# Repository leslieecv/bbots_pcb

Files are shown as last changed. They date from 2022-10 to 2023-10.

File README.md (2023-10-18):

# PCB Battlebots base

Este repositorio contiene las diferentes versiones de placa base, diseñadas para el curso [Battlebots](https://github.com/Battlebots-UChile) de la FCFM Uchile.
Fueron desarrolladas usando EAGLE y se complementa con el diseño

- pcbv1: utiliza Arduino UNO (funcional). Otros detalles disponibles en [Battlebot-base-testing](https://github.com/uwulises/Battlebot-base-testing).
- pcbv2: utiliza NodeMCU Amica V2 (ESP8266) y opcionalmente puede usar un Módulo Wifi ESP8266 ESP-07 (incompleta).
- pcbv3: utiliza solamente NodeMCU Amica V2 (ESP8266) (funcional). Diseño mecánico disponible en [MobileBase_ESP8266](https://github.com/uwulises/MobileBase_ESP8266).

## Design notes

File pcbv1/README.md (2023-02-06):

# Placa Battlebots 

Hola, soy una placa que busca integrar los componentes del BattleBot base entregado a estudiantes del curso Módulo Interdisciplinario - Battlebots 2022.

La placa considera la conexión con los siguiente componentes:
- Arduino UNO (1)
- Driver Puente H L9110S (2)
- Módulo Bluetooth HC-06 (1)
- Regulador de voltaje LM2596 (1)
- Regulador de voltaje LM2596 Mini (1)
- Batería LiPo de 7.4V (1)

Adicionalmente, se tienen componentes accesorios:
- Led SMD 0805 (2)
- Resistencia SMD 0805 de 0.5-1kOhm (2)
- Diodo (1)

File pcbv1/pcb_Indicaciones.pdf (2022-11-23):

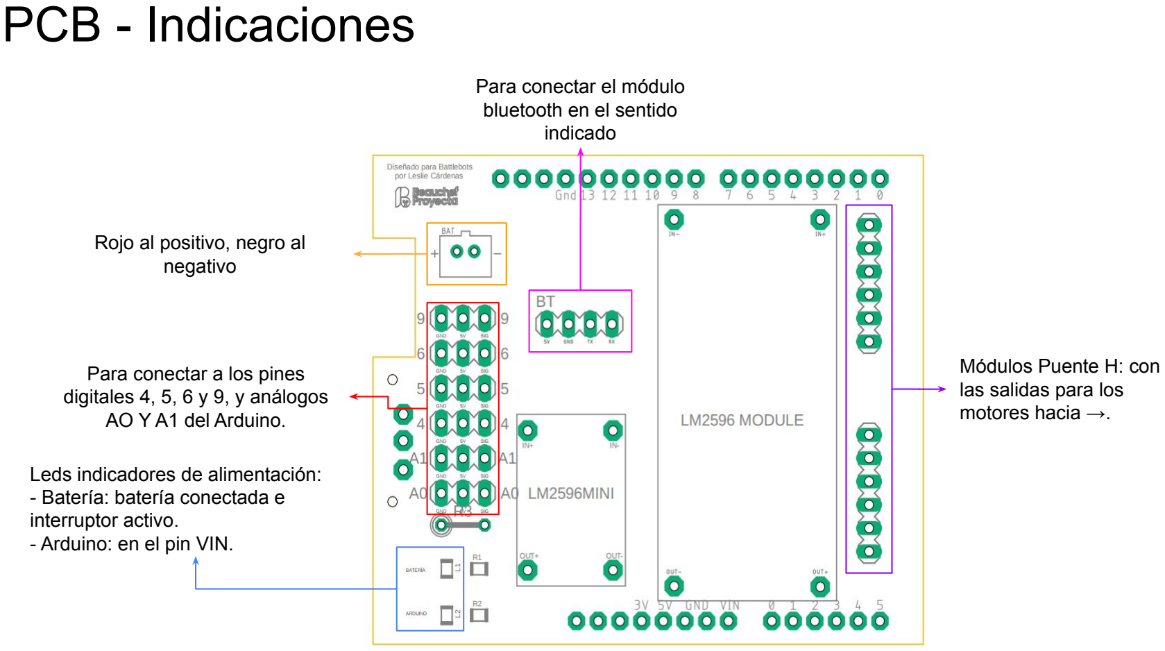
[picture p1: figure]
Para conectar a los pines digitales 4, 5, 6 y 9, y análogos AO Y A1 del Arduino.; Rojo al positivo, negro al negativo; Leds indicadores de alimentación: - Batería: batería conectada e interruptor activo. - Arduino: en el pin VIN.; Módulos Puente H: con las salidas para los motores hacia →.; Para conectar el módulo bluetooth en el sentido indicado; PCB - Indicaciones

# PCB - Puente H y conexiones con motores

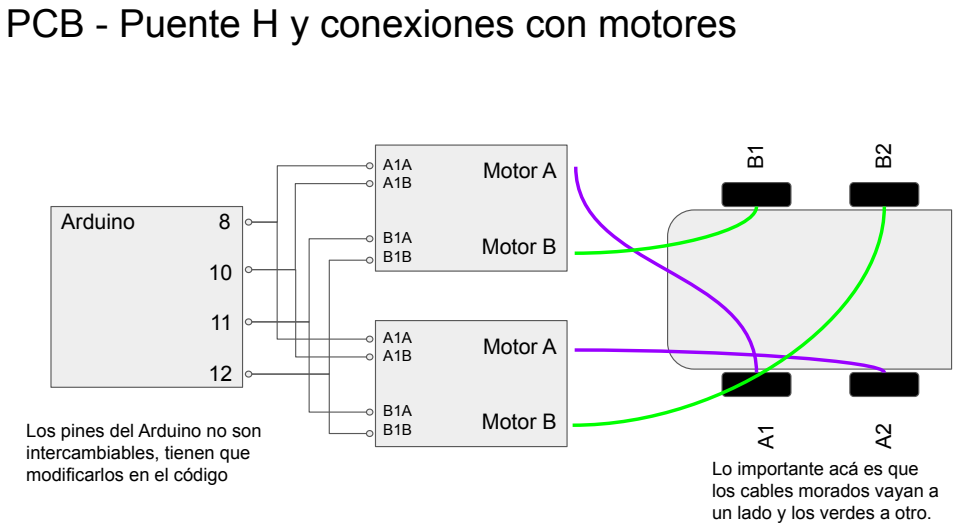
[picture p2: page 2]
Motor A; Motor B; Arduino; Los pines del Arduino no son; modificarlos en el código; Lo importante acá es que

intercambiables, tienen que

los cables morados vayan a
un lado y los verdes a otro.

# PCB - Módulo Bluetooth

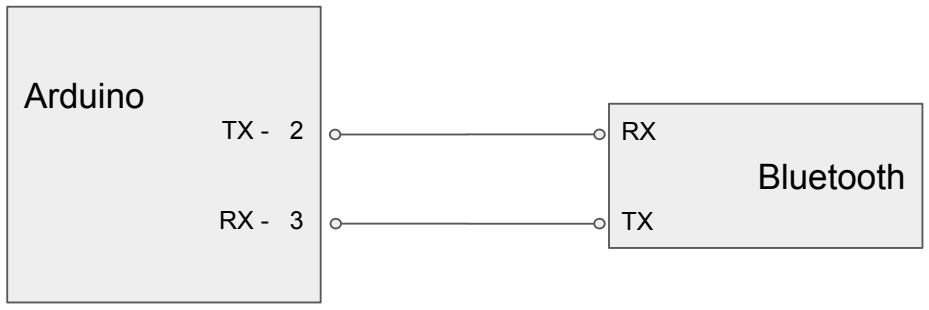
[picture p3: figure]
Bluetooth; Arduino

### Deben usar la librería SofwareSerial para configurar los pines 2 y 3 del

Arduino como TX y RX,

### respectivamente

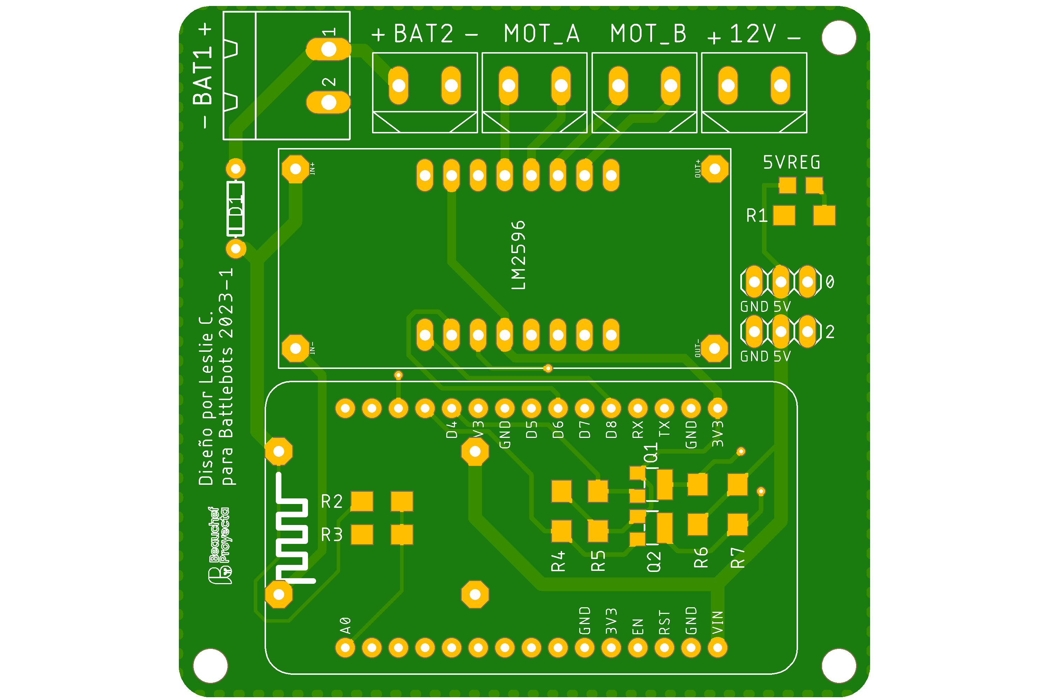
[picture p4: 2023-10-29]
pcbv3/top.png

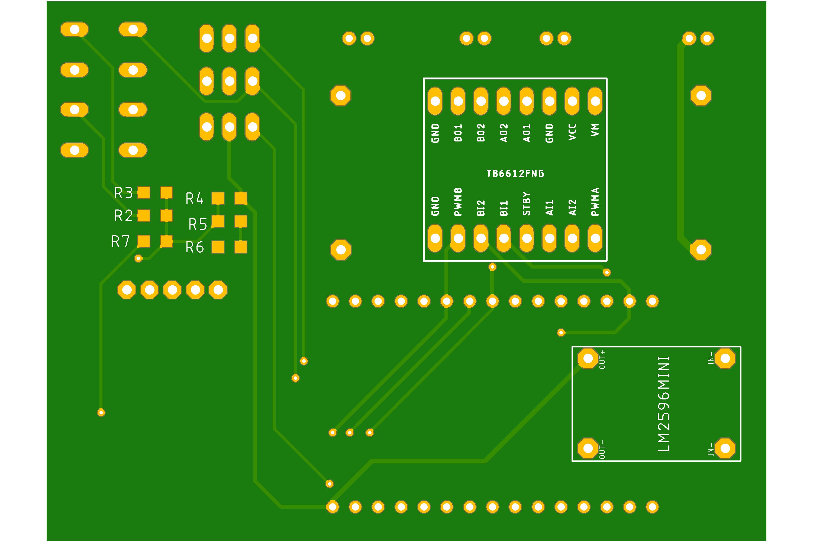
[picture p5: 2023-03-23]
pcbv2/bbotsv2_bottom.png

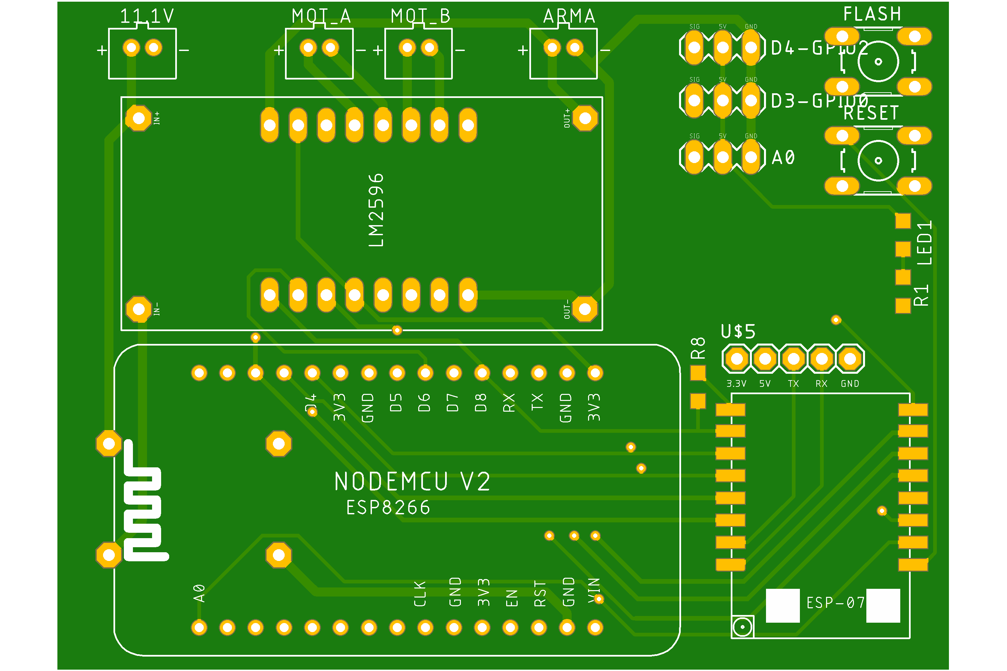
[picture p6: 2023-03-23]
pcbv2/bbotsv2_top.png

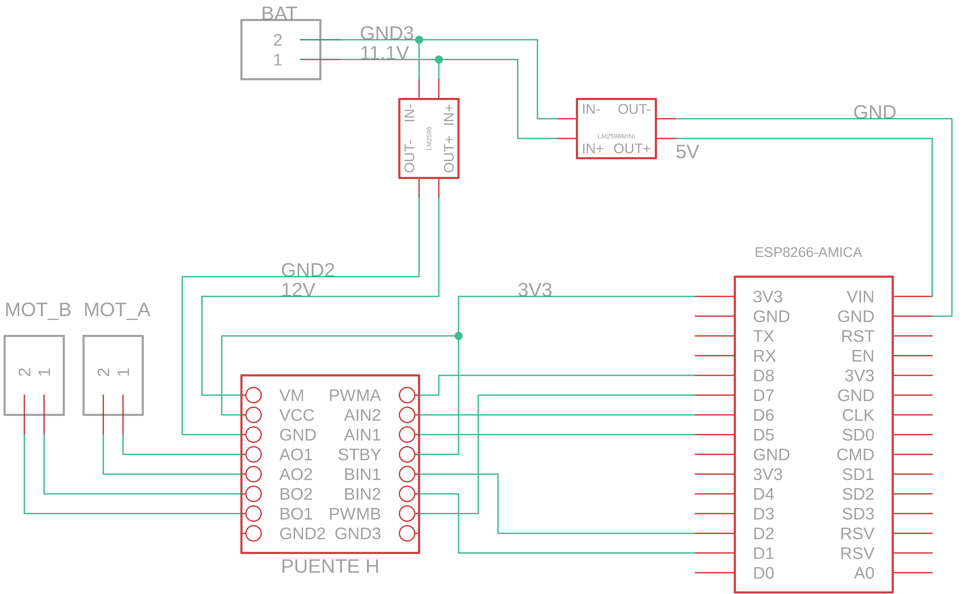
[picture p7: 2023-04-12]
prepcb diagram/diagram_light.png

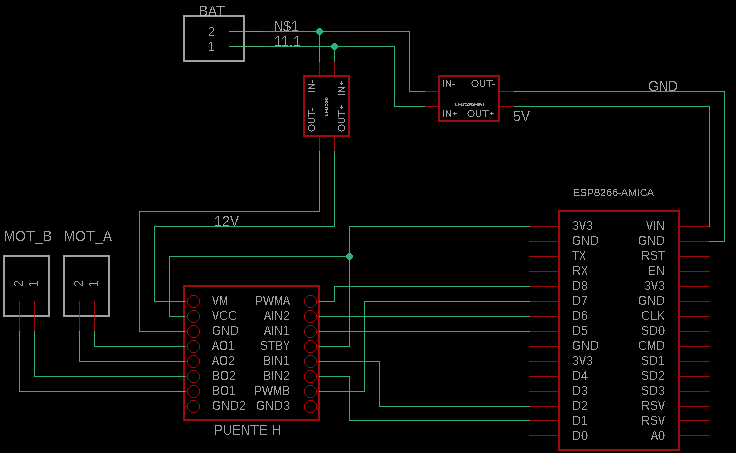
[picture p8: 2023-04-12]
prepcb diagram/diagram.png

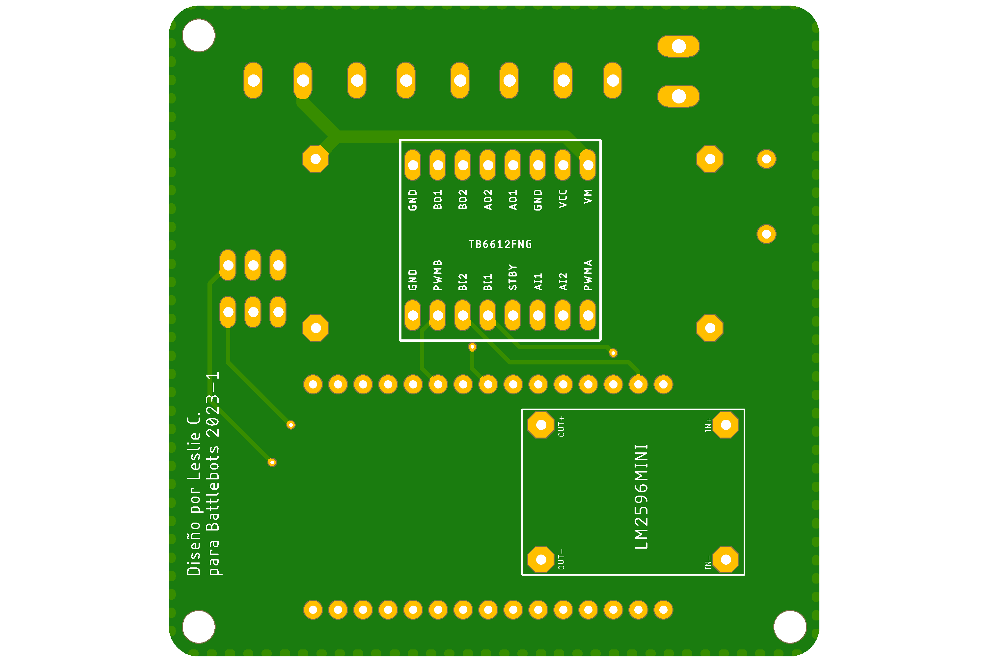
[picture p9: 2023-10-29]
pcbv3/bottom.png

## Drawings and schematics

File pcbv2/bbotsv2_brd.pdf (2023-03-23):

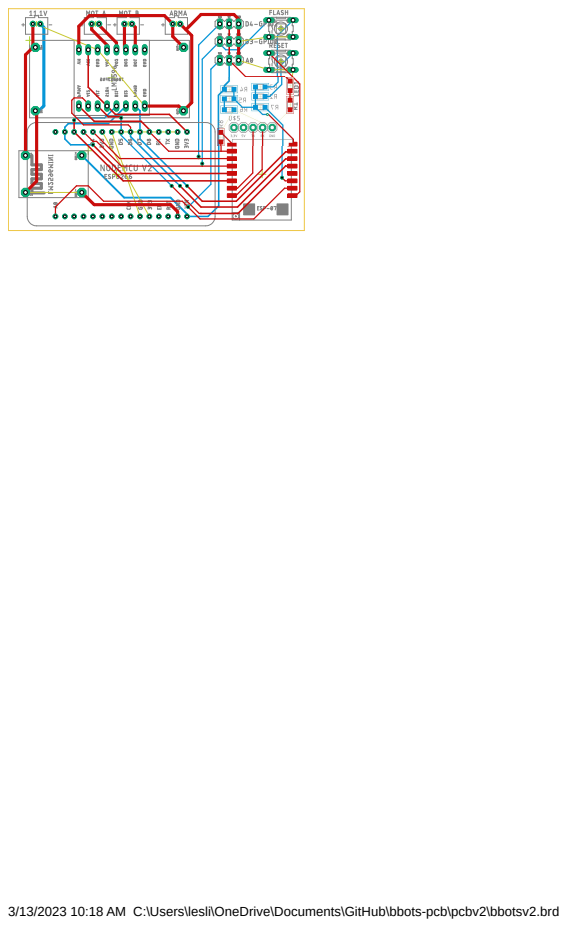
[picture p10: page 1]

3/13/2023 10:18 AM C:\Users\lesli\OneDrive\Documents\GitHub\bbots-pcb\pcbv2\bbotsv2.brd

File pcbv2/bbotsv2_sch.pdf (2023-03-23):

# 4 2 FLASHR³

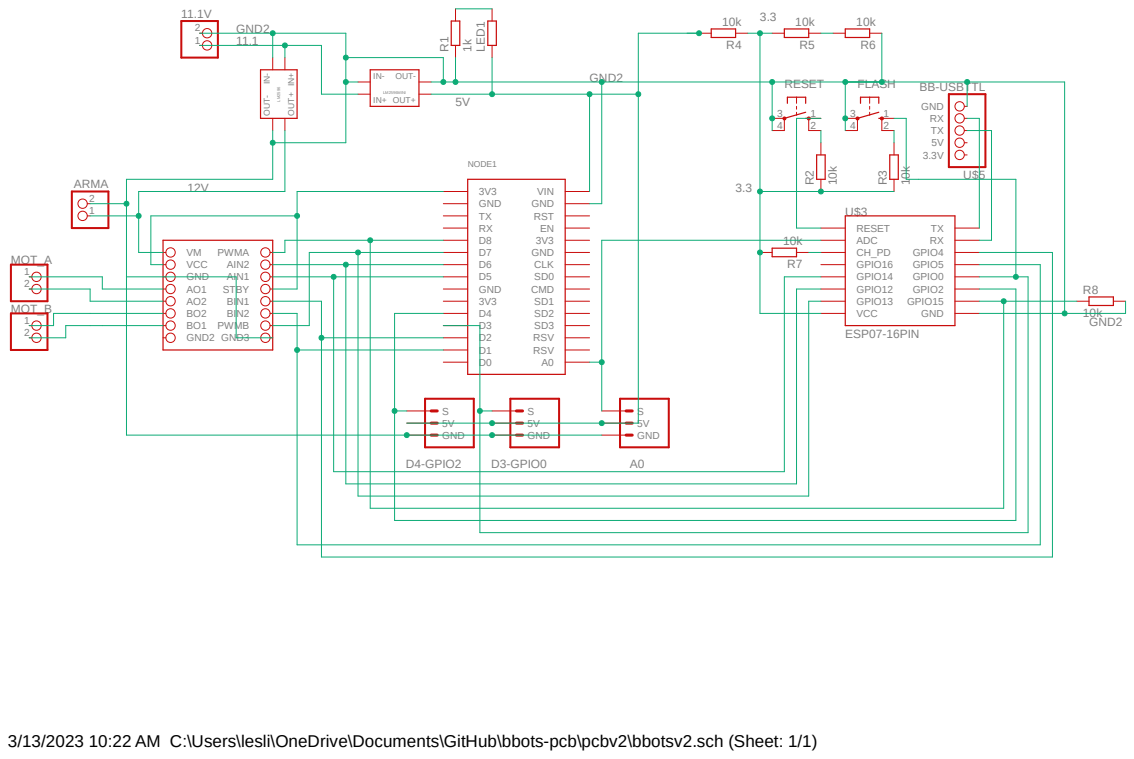
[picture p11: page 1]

NODE1 IN⁺ OUT+ IN⁻ OUT⁻ LM²⁵⁹⁶

3/13/2023 10:22 AM C:\Users\lesli\OneDrive\Documents\GitHub\bbots-pcb\pcbv2\bbotsv2.sch (Sheet: 1/1)

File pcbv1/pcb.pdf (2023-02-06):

# Diseñado para Battlebots por Leslie Cárdenas

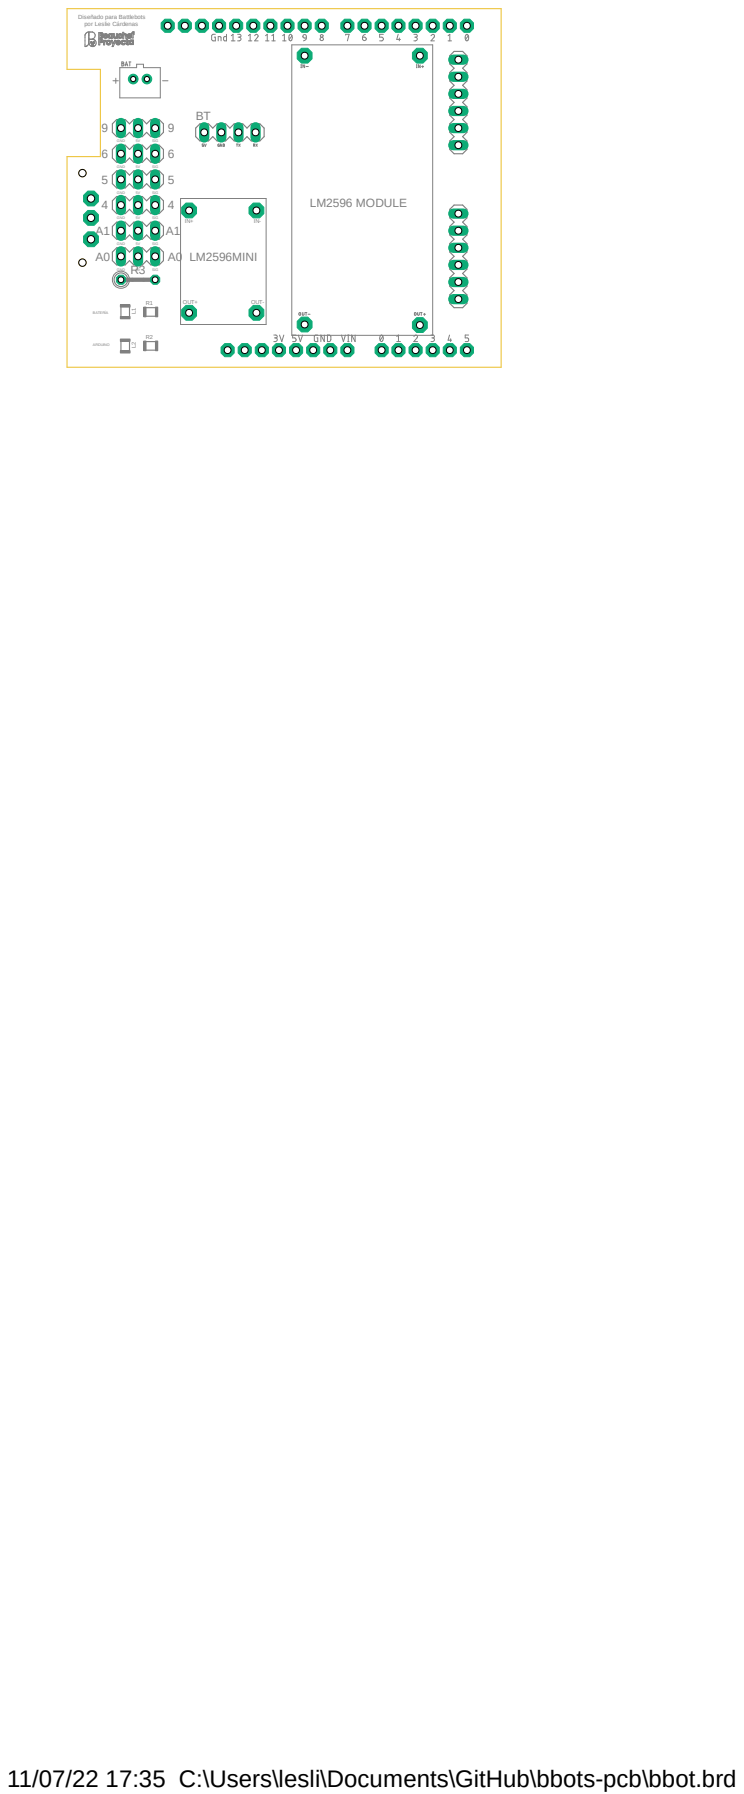
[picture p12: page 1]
ARDUINO; BATERÍA; OUT+; OUT-; LM2596MINI; GND; SIG; LM2596 MODULE

11/07/22 17:35 C:\Users\lesli\Documents\GitHub\bbots-pcb\bbot.brd

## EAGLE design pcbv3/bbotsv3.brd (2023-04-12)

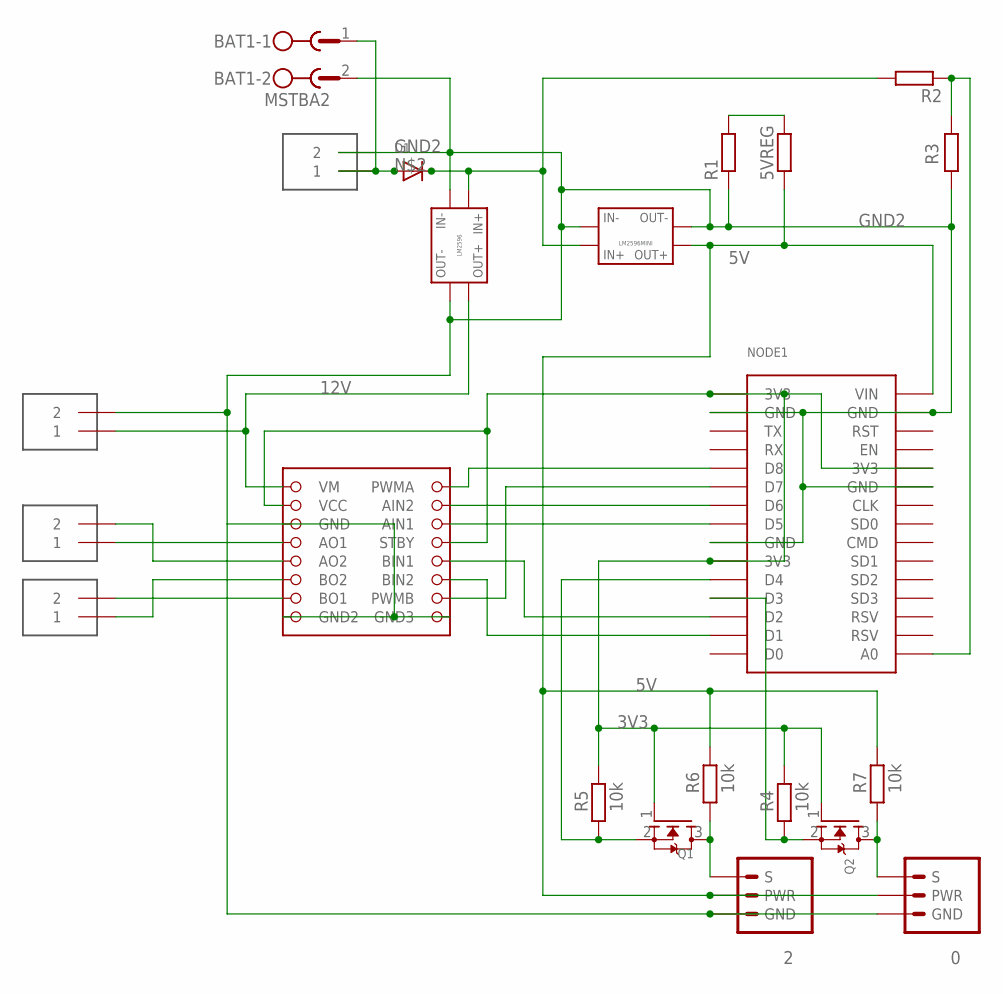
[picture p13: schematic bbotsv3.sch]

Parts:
0, 2: BB-PIN3BB-PIN3; 1X03
5VREG: BB-R0805; R0805
ARMA, ARMA1, ARMA2, ARMA3: TERMINAL_2P; KF301-2P
BAT1: MSTBA2
D1: DIODEDO-1N4148; DO-1N4148
NODE1: NODEMCU_ESP8266
Q1, Q2: MOSFET-NWAVE; SOT23-W
R1: 100; R1206
R2, R4, R5, R6, R7: 10k; R1206
R3: 1k; R1206
U$1: BB-LM2596
U$2: BB-TB6612
U$3: BB-LM2596MINILM2596MINIV2; LM2596MINIV2

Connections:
3V3: NODE1.3V3@1 (3V3), NODE1.3V3@2 (3V3), NODE1.3V3@3 (3V3), Q1.1 (G), Q2.1 (G), R4.2, R5.2, U$2.STBY, U$2.VCC
5V: 0.P (PWR), 2.P (PWR), 5VREG.1, NODE1.VIN, R6.2, R7.2, U$3.OUT+
11.1: D1.C, R2.2, U$1.IN+, U$3.IN+
12V: ARMA.1, U$1.OUT+, U$2.VM
GND2: 0.GND, 2.GND, ARMA.2, ARMA3.2, BAT1.2, NODE1.GND@1 (GND), NODE1.GND@2 (GND), NODE1.GND@3 (GND), NODE1.GND@4 (GND), R1.1, R3.2, U$1.IN-, U$1.OUT-, U$2.GND, U$2.GND2, U$2.GND3, U$3.IN-, U$3.OUT-
unnamed: NODE1.A0, R2.1, R3.1
unnamed: ARMA3.1, BAT1.1, D1.A
unnamed: 5VREG.2, R1.2
unnamed: NODE1.D8, U$2.PWMA
unnamed: NODE1.D7, U$2.PWMB
unnamed: ARMA2.1, U$2.BO2
unnamed: NODE1.D6, U$2.AI2 (AIN2)
unnamed: NODE1.D5, U$2.AI1 (AIN1)
unnamed: NODE1.D2, U$2.BI1 (BIN1)
unnamed: NODE1.D1, U$2.BI2 (BIN2)
unnamed: 2.S, Q1.3 (D), R6.1
unnamed: NODE1.D3, Q2.2 (S), R4.1
unnamed: ARMA1.2, U$2.AO2
unnamed: ARMA1.1, U$2.AO1
unnamed: ARMA2.2, U$2.BO1
unnamed: 0.S, Q2.3 (D), R7.1
unnamed: NODE1.D4, Q1.2 (S), R5.1

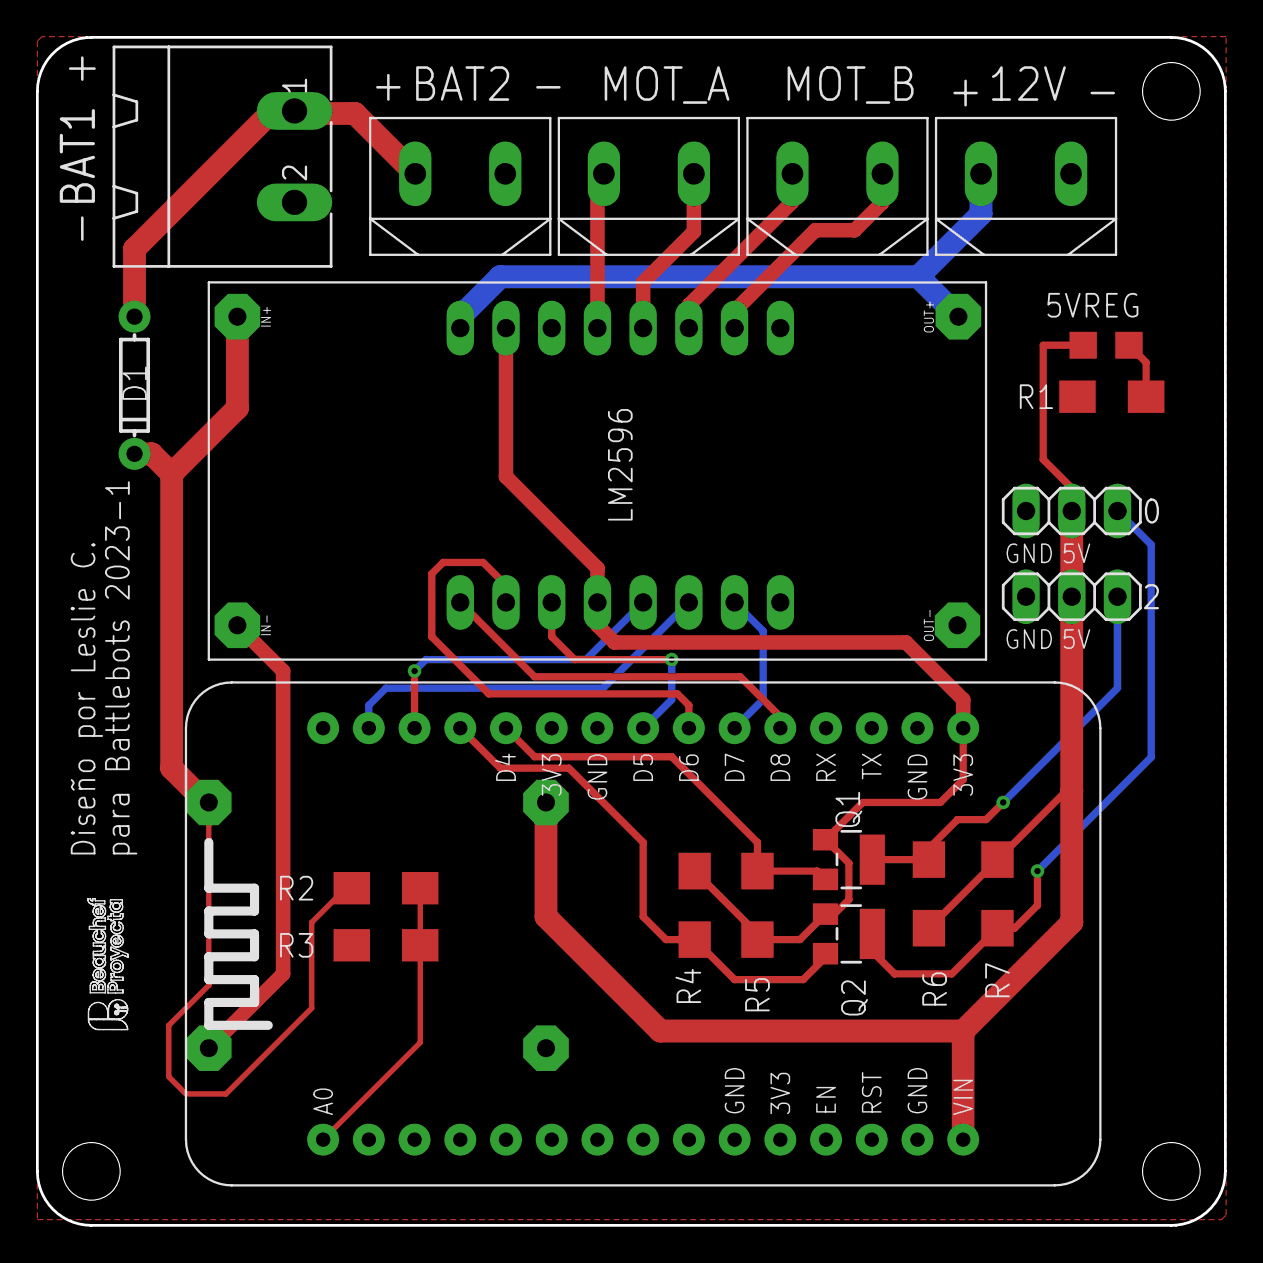
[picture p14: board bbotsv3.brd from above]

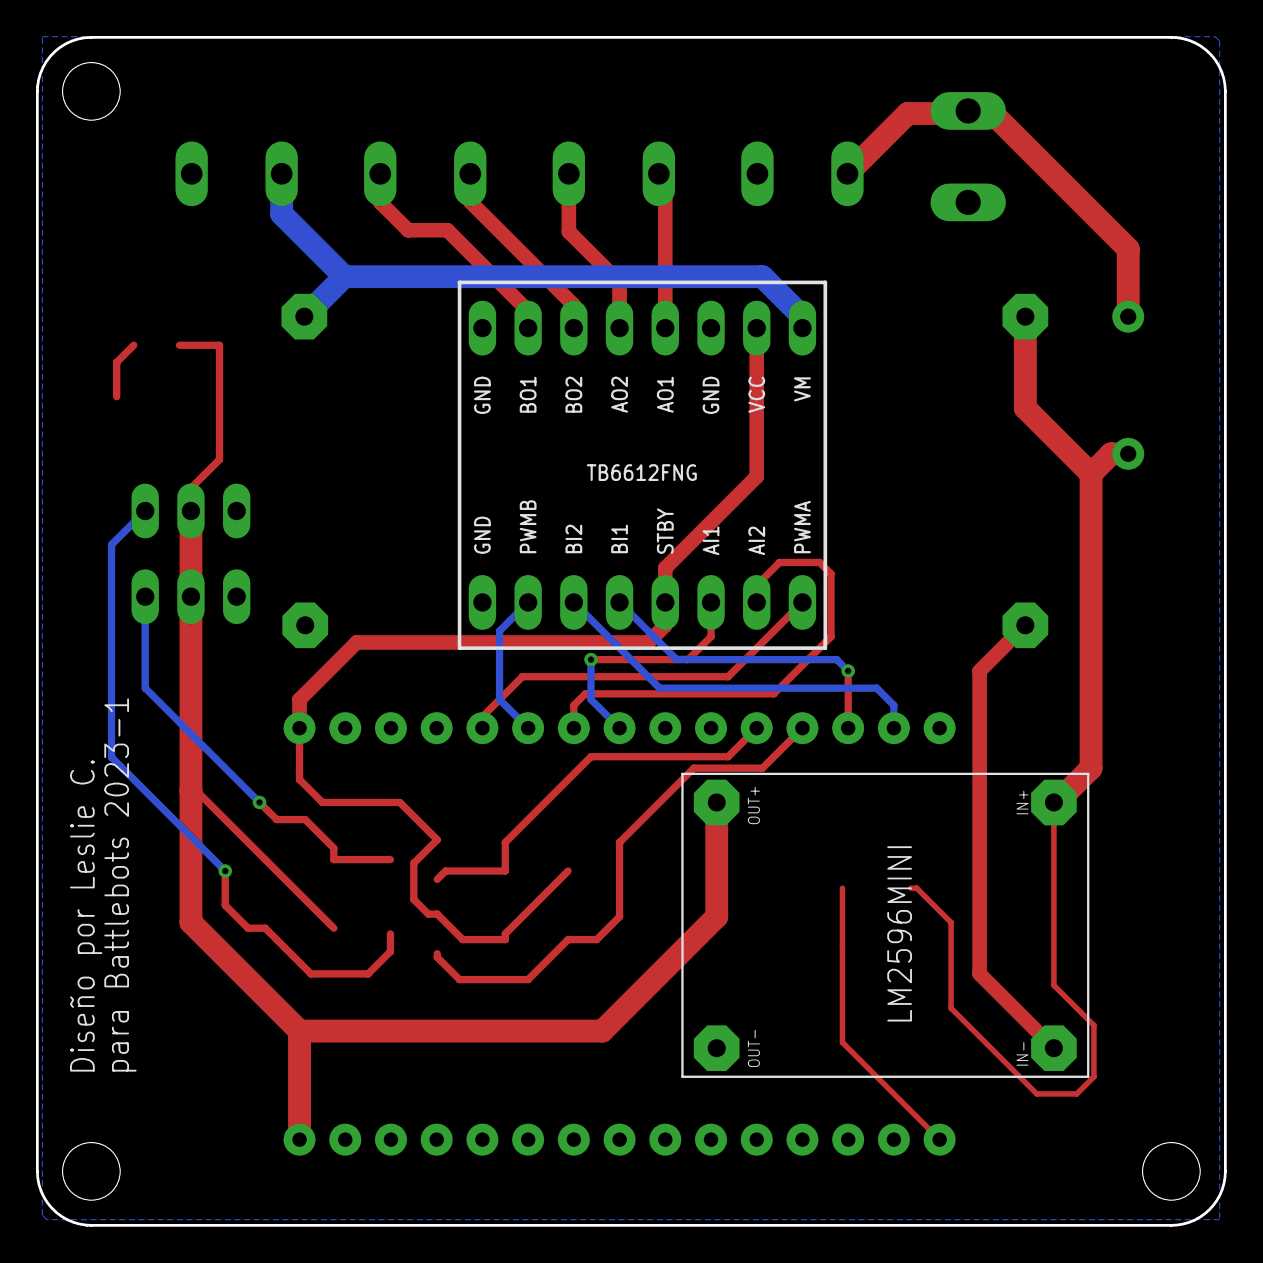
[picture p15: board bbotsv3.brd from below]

Board: 2 copper layers, 66.0 x 66.0 mm, 22 parts (2 on the bottom side), 22 nets.

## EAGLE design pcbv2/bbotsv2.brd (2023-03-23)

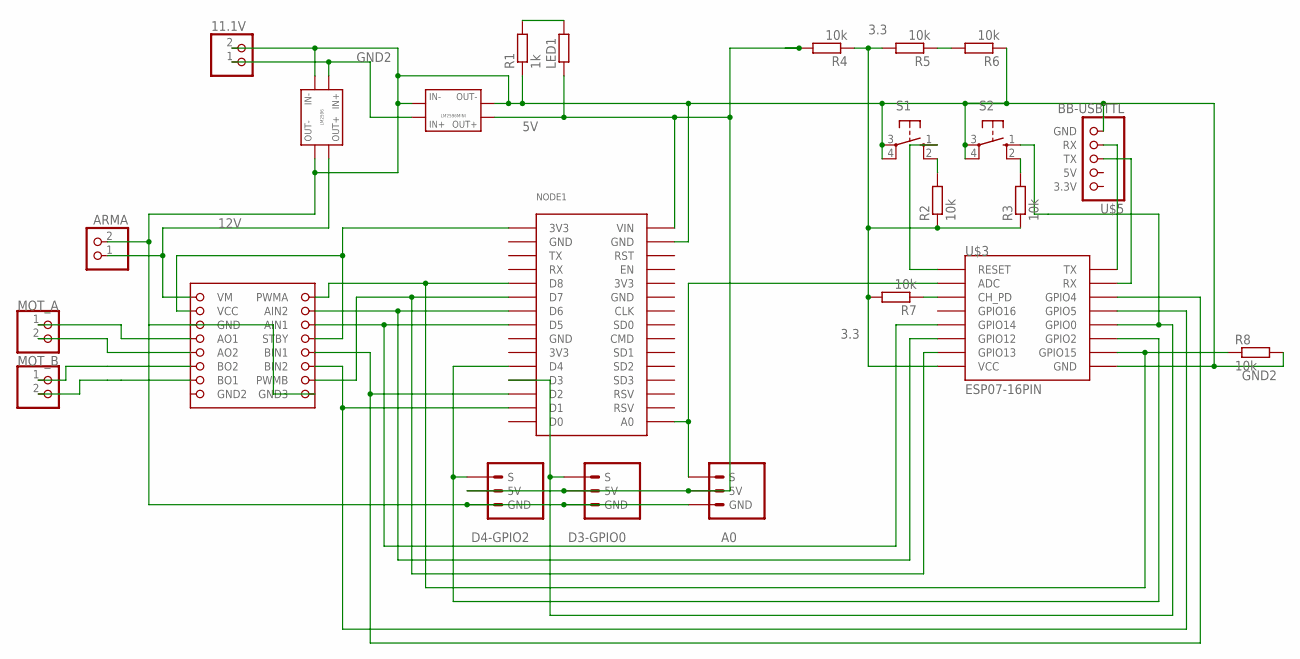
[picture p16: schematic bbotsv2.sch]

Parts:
11.1V: JST_2PIN-THM; JST-PH-2-THM
A0: BB-PIN3
ARMA: JST_2PIN-THM; JST-PH-2-THM
D3-GPIO0, D4-GPIO2: BB-PIN3
LED1: BB-RESM0805; M0805
MOT_A: JST_2PIN-THM; JST-PH-2-THM
MOT_B: JST_2PIN-THM; JST-PH-2-THM
NODE1: NODEMCU_ESP8266
R1: 1k; M0805
R2, R3, R4, R5, R6, R7, R8: 10k; M0805
S1, S2: 10-XX; B3F-10XX
U$1: BB-LM2596
U$2: BB-TB6612
U$3: ESP07-16PIN
U$4: BB-LM2596MINI
U$5: BB-USBTTL; 1X05

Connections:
3.3: R2.1, R3.1, R4.1, R5.2, R7.2, U$3.VCC
3V3: NODE1.3V3@2 (3V3), NODE1.3V3@3 (3V3)
5V: A0.2 (5V), D3-GPIO0.2 (5V), D4-GPIO2.2 (5V), LED1.1, NODE1.VIN, R4.2, U$4.OUT+
11.1: 11.1V.1 (2), U$1.IN+, U$4.IN+
12V: ARMA.1 (2), U$1.OUT+, U$2.VM
GND: NODE1.GND@1 (GND), NODE1.GND@2 (GND), NODE1.GND@3 (GND)
GND2: 11.1V.2 (1), A0.1 (GND), ARMA.2 (1), D3-GPIO0.1 (GND), D4-GPIO2.1 (GND), NODE1.GND@4 (GND), R1.1, R6.1, R8.2, S1.3, S1.4 (P1), S2.3, S2.4 (P1), U$1.IN-, U$1.OUT-, U$2.GND, U$2.GND3, U$3.GND, U$4.IN-, U$4.OUT-, U$5.GND; also elsewhere on the board
unnamed: LED1.2, R1.2
unnamed: NODE1.D8, R8.1, U$2.PWMA, U$3.GPIO15
unnamed: NODE1.D7, U$2.PWMB, U$3.GPIO13
unnamed: NODE1.D6, U$2.AI2 (AIN2), U$3.GPIO12
unnamed: NODE1.D5, U$2.AI1 (AIN1), U$3.GPIO14
unnamed: NODE1.D2, U$2.BI1 (BIN1), U$3.GPIO4
unnamed: NODE1.D1, U$2.BI2 (BIN2), U$3.GPIO5
unnamed: D4-GPIO2.3 (S), NODE1.D4, U$3.GPIO2
unnamed: MOT_A.2 (1), U$2.AO2
unnamed: MOT_A.1 (2), U$2.AO1
unnamed: MOT_B.1 (2), U$2.BO2
unnamed: MOT_B.2 (1), U$2.BO1
unnamed: NODE1.3V3@1 (3V3), U$2.STBY, U$2.VCC
unnamed 20: D3-GPIO0.3 (S), NODE1.D3, S2.1 (S), U$3.GPIO0; also elsewhere on the board
unnamed: U$3.TX, U$5.RX
unnamed: U$3.RX, U$5.TX
unnamed: A0.3 (S), NODE1.A0, U$3.ADC
unnamed 24: R2.2, S1.2 (S1); also elsewhere on the board
unnamed 25: R3.2, S2.2 (S1); also elsewhere on the board
unnamed: R5.1, R6.2
unnamed 27: S1.1 (S), U$3.REST (RESET); also elsewhere on the board
unnamed: R7.1, U$3.CH_PD

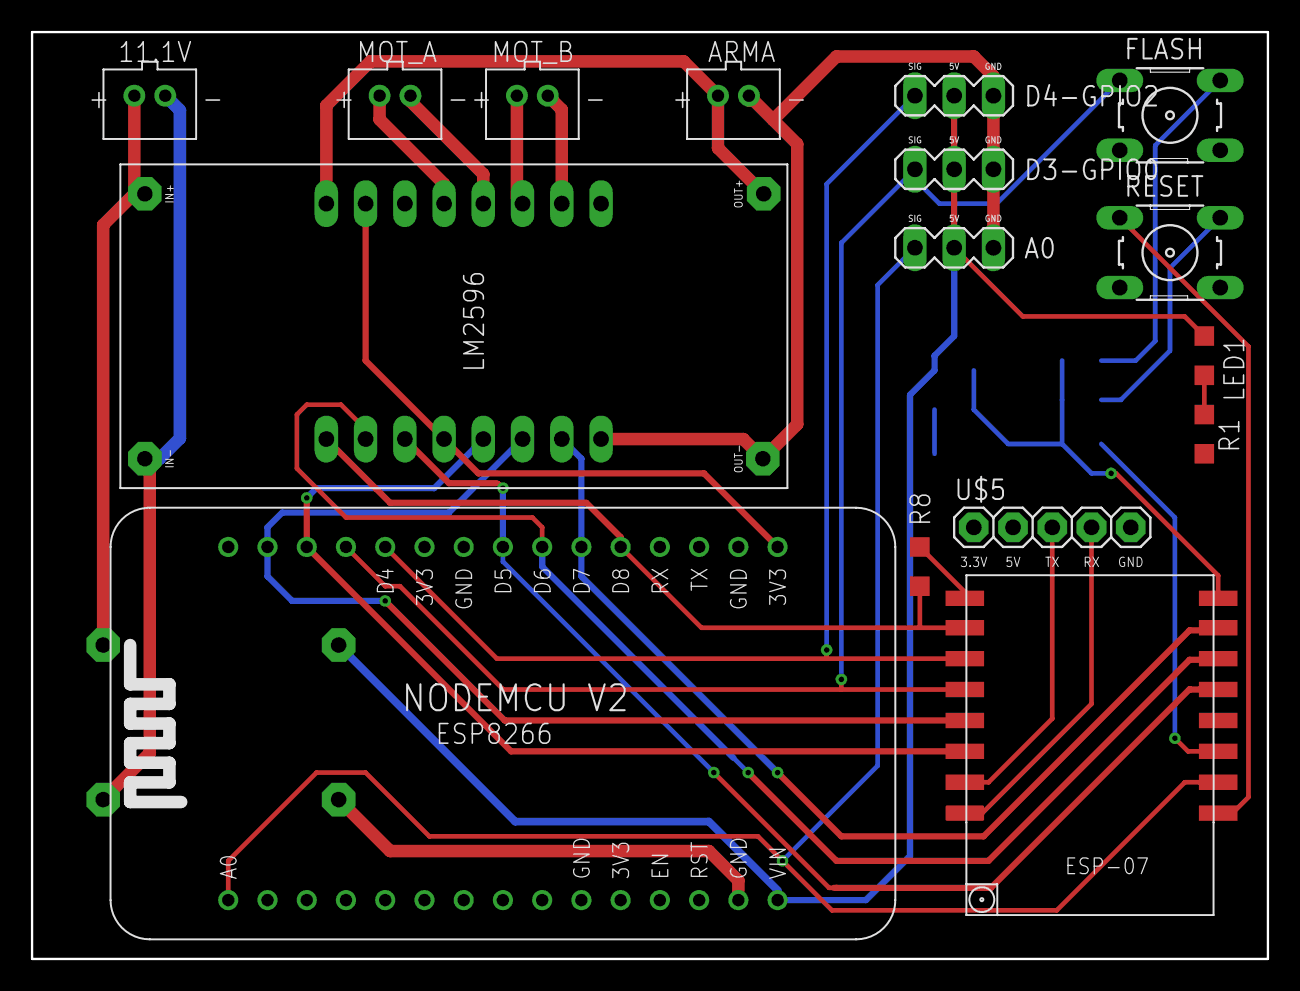
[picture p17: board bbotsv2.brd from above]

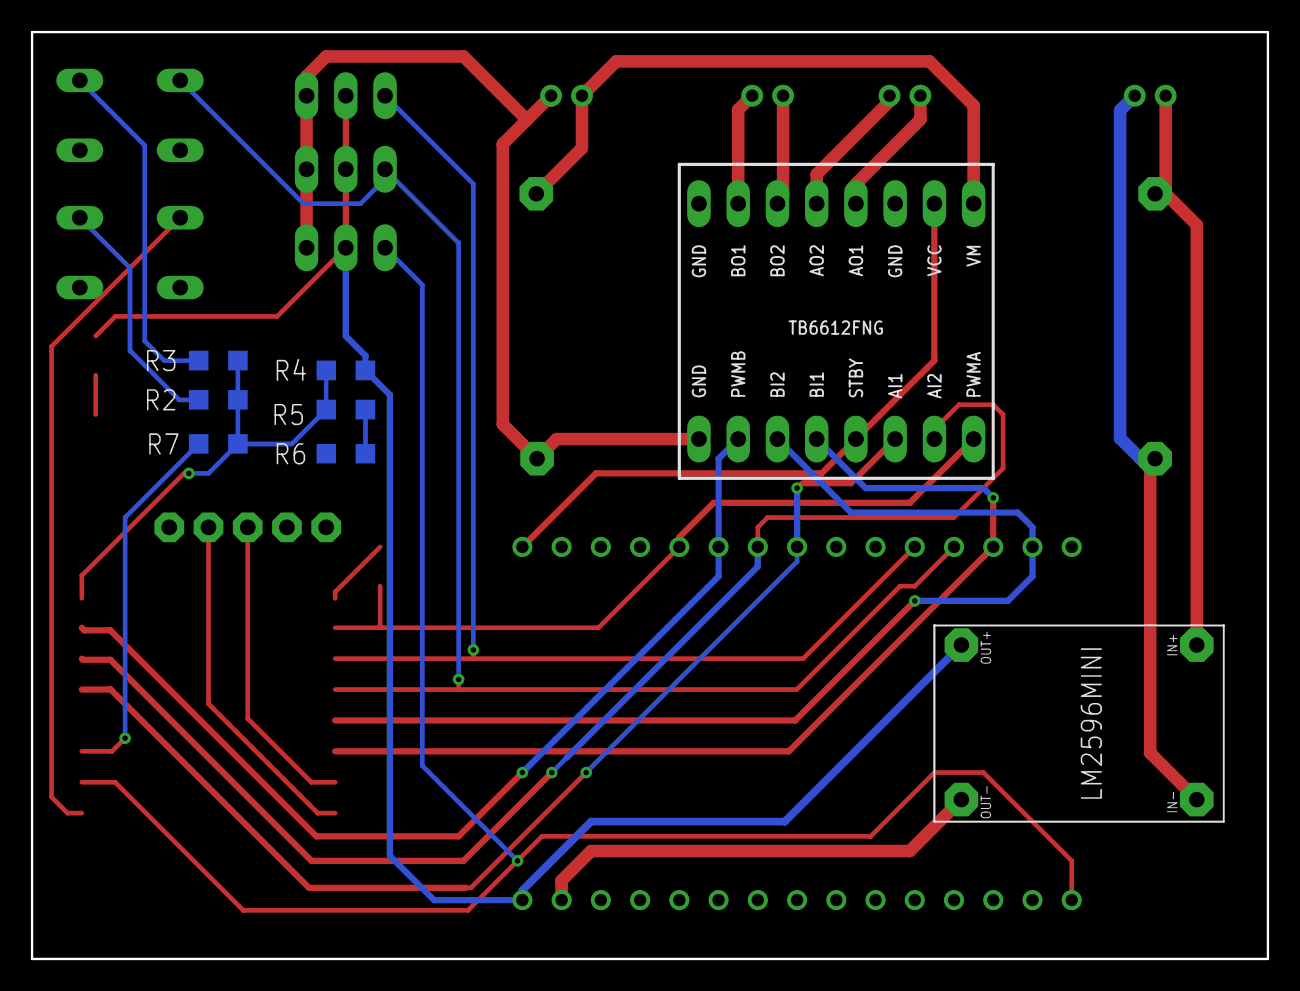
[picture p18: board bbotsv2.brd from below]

Board: 2 copper layers, 80.0 x 60.0 mm, 24 parts (8 on the bottom side), 29 nets.

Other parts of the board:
FLASH: B3F-10XX
RESET: B3F-10XX

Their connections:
GND2: FLASH.3, FLASH.4, RESET.3, RESET.4; also elsewhere on the board
unnamed 20: FLASH.1; also elsewhere on the board
unnamed 24: RESET.2; also elsewhere on the board
unnamed 25: FLASH.2; also elsewhere on the board
unnamed 27: RESET.1; also elsewhere on the board

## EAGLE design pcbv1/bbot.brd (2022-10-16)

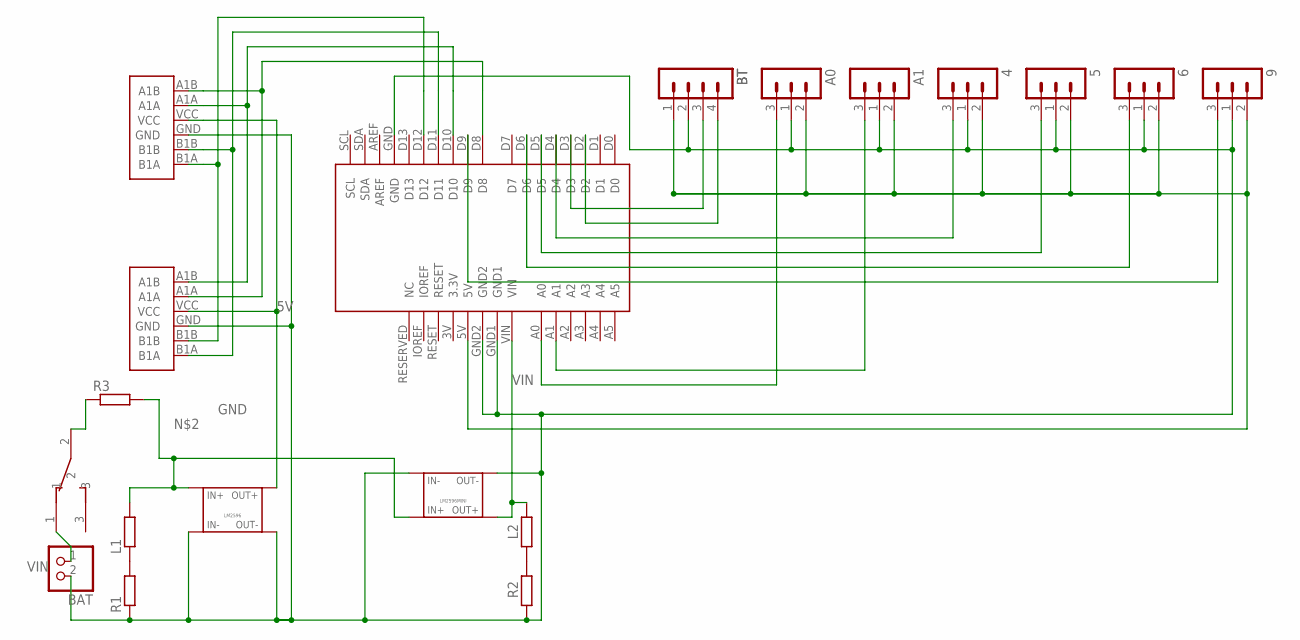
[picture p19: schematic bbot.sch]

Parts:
4, 5, 6, 9: BB-PIN3
A0, A1: BB-PIN3
BAT: VIN; JST-PH-2-THM
BT: BB-HC06
L1, L2: BB-RESM0805; M0805
LM2596: BB-LM2596
LM2596MINI: BB-LM2596MINI
R1, R2: BB-RESM0805; M0805
R3: R-EU_0207/5V; 0207/5V
SW1: BB-SWITCHBB-SW; BB-SWITCH
U$1: BB-ARD
U$2, U$3: BB-PTEH

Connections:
5V: LM2596.OUT+, U$2.VCC, U$3.VCC
5V-A: 4.2 (5V), 5.2 (5V), 6.2 (5V), 9.2 (5V), A0.2 (5V), A1.2 (5V), BT.1, U$1.5V
7.4V: L1.2, LM2596.IN+, LM2596MINI.IN+, R3.2
GND: 4.1 (GND), 5.1 (GND), 6.1 (GND), 9.1 (GND), A0.1 (GND), A1.1 (GND), BAT.2 (1), BT.2, LM2596.IN-, LM2596.OUT-, LM2596MINI.IN-, LM2596MINI.OUT-, R1.1, R2.1, U$1.GND, U$1.GND1, U$1.GND2, U$2.GND, U$3.GND
unnamed: BT.3, U$1.D3
unnamed: R3.1, SW1.2
unnamed: L1.1, R1.2
unnamed: 9.3 (S), U$1.D9
unnamed: BAT.1 (2), SW1.1
unnamed: U$1.D11, U$2.B1B, U$3.B1A
unnamed: BT.4, U$1.D2
unnamed: U$1.D12, U$2.B1A, U$3.B1B
unnamed: U$1.D10, U$2.A1A, U$3.A1B
unnamed: U$1.D8, U$2.A1B, U$3.A1A
unnamed: 6.3 (S), U$1.D6
unnamed: 5.3 (S), U$1.D5
unnamed: 4.3 (S), U$1.D4
unnamed: A1.3 (S), U$1.A1
unnamed: A0.3 (S), U$1.A0
unnamed: L2.1, R2.2
VIN: L2.2, LM2596MINI.OUT+, U$1.VIN

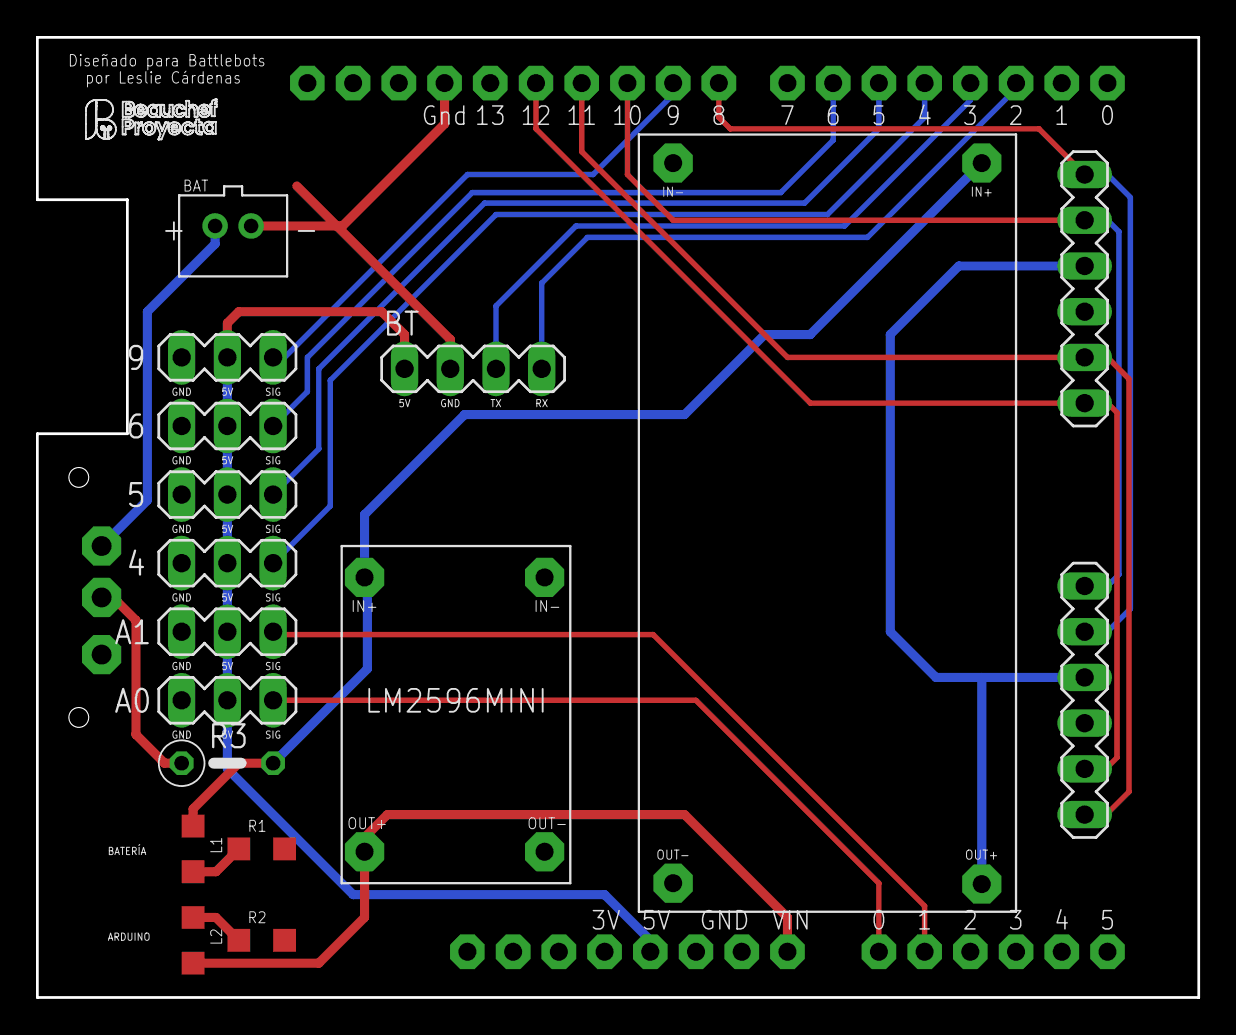
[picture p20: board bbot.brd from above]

Board: 2 copper layers, 64.5 x 53.3 mm, 19 parts (0 on the bottom side), 21 nets.

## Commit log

2022-09-20 added new files
    [bbot.brd, bbot.sch]
2022-09-20 added lm2596, everything is working
    [bbot.brd, bbot.sch]
2022-09-21 added some tags to brd
    [bbot.brd, bbot.sch]
2022-09-26 changed footprint arduino and h bridge, and added more tags
    [bbot.brd, bbot.sch]
2022-10-11 added bp label and diode
    [bbot.brd, bbot.sch]
2022-10-16 added bp logo, ready to manufacture
    [bbot.brd]
2023-02-06 started pcb v2 2023
    [bbot.brd, bbot.sch, bbotsv2.brd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]
2023-03-12 connected everything to amica, not tested
    [bbotsv2.brd, bbotsv2.sch]
2023-03-13 connected esp07 on schematic and ruted all components
    [bbotsv2.brd, bbotsv2.sch]
2023-03-23 changed version of lm2596mini
    [bbotsv2.brd, bbotsv3.brd, bbotsv3.sch]
2023-03-28 added connections for voltage tester
    [bbotsv3.brd, bbotsv3.sch]
2023-03-31 finish pcb, waiting review
    [bbotsv3.brd, bbotsv3.sch]
2023-04-03 ready to manufacture, review done
    [bbotsv3.brd, bbotsv3.sch]
2023-04-12 last update of pcbv3, add gerber/zip file for manufacture
    [bbotsv3.brd, prepcb.sch]
2023-10-29 add pcb images
